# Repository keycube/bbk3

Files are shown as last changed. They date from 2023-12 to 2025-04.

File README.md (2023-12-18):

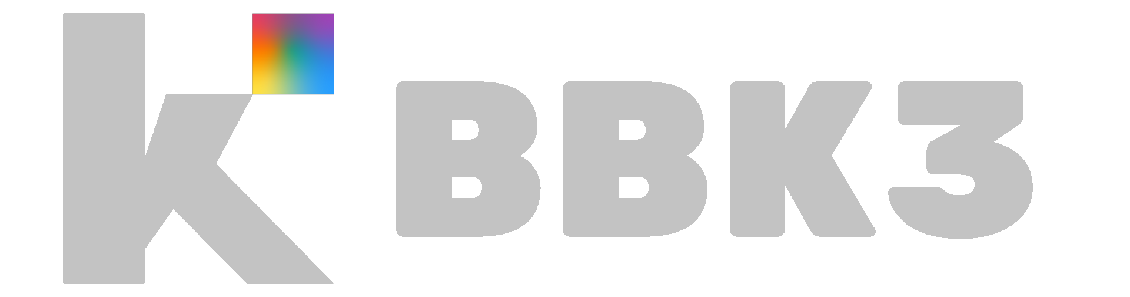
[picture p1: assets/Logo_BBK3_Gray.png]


# Introduction

The BBK3 (BabyCube) is the miniature derivative of the K3. Thanks to these 5 keys, its gyroscope and accelerator, you can control a multitude of applications thanks to its bluetooh connection.

# 3D model

The 3D models were made with Fusion 360. The models have been tested with a resin printer but are intended for an FDM printer. (The colors are present to facilitate the 3D preview, you are free to choose when printing.)

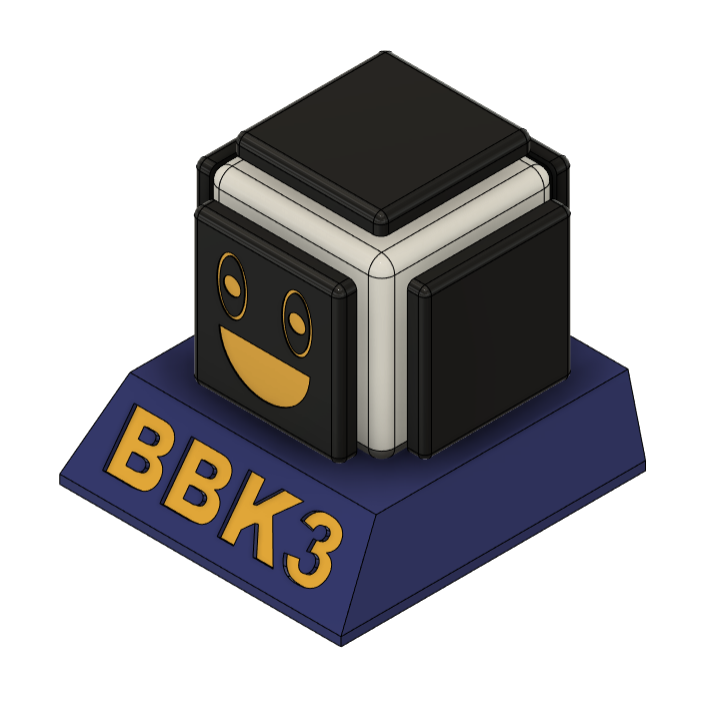
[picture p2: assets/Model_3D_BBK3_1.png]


**Below**

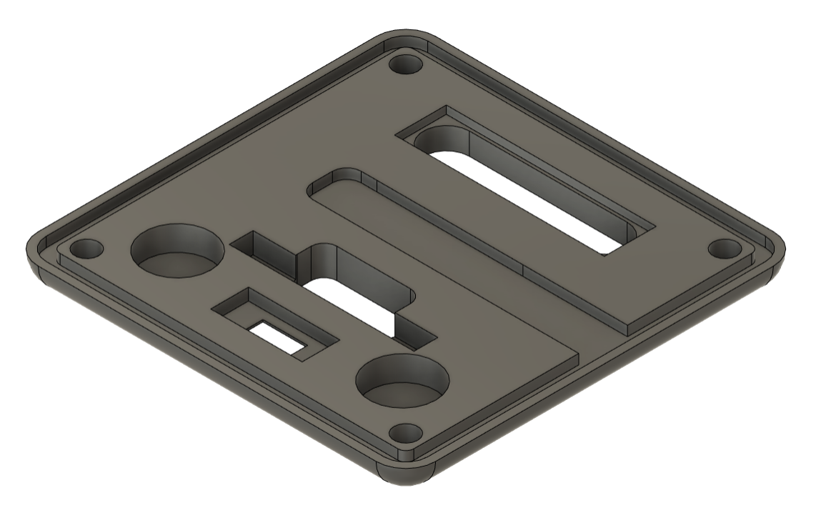
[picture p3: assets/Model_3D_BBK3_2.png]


**Above**

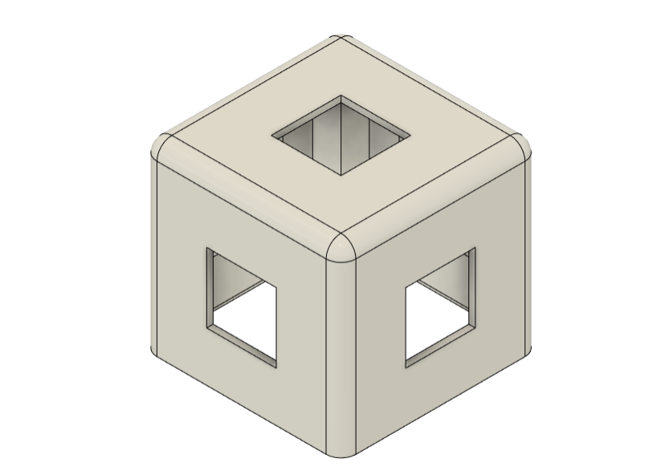
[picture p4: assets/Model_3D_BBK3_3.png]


**Support**

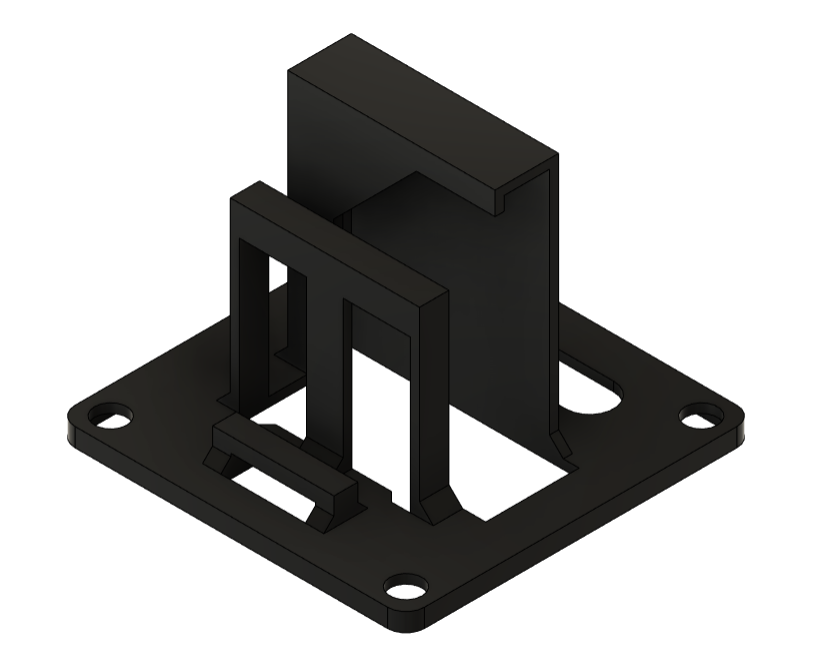
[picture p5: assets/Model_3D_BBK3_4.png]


**Keys**

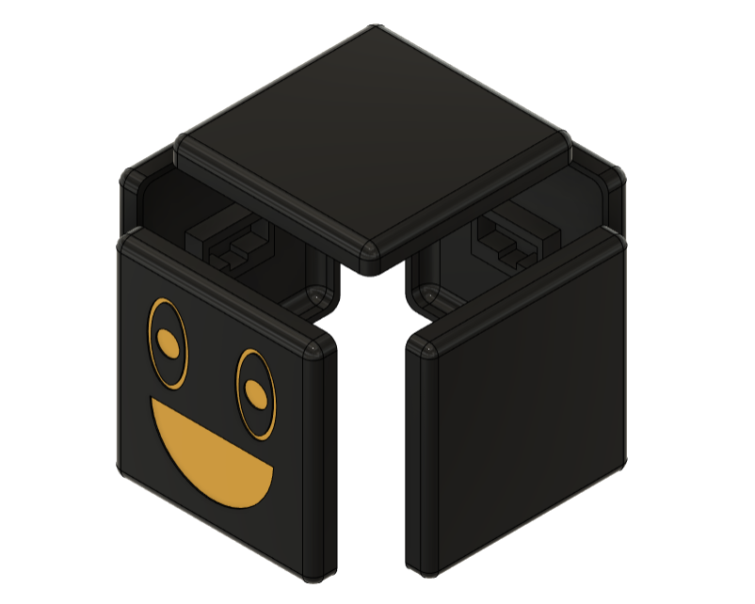
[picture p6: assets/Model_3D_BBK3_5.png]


# Electronic components

The components listed below were chosen according to our desires, the dimensions in the 3D models were made accordingly. If you want to choose other electronic components, don't forget to modify the 3D models.

**Microcontroller**: https://www.seeedstudio.com/Seeed-XIAO-BLE-Sense-nRF52840-p-5253.html

**Magnetic connection**: https://www.adafruit.com/product/5413

**Battery**: https://www.adafruit.com/product/1317

**Keys**: https://www.adafruit.com/product/5113

**Keys Sockets**: https://www.adafruit.com/product/5756

**Magnets**: https://www.amazon.fr/Deryun-aimants-puissants-n%C3%A9odyme-r%C3%A9frig%C3%A9rateur/dp/B0936VD5N4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

# Tutorial

..._TODO_...

# Code

To code, I used the Arduino IDE. I coded the code "BBK3.ino" as an example.

**- Connection**: The microcontroller creates a Bluetooth connection to be able to connect.

**- Light animation**: The cube flashes red until it is connected and reacts green once it is. When the keys are not pressed, the LEDs are orange and when a key is clicked, the corresponding key is white. After 7 seconds without clicking, the keys turn red and create the animation of a beating heart, returning to normal at the slightest click.

**- Actuators**: The gyroscope is used to move the mouse. The keys simulate the keyboard with Z, Q, S, D and left click on the top key.

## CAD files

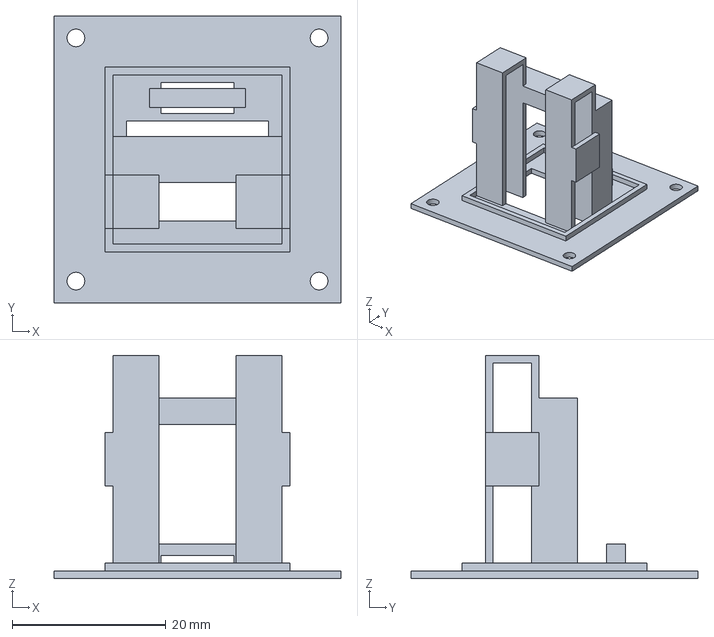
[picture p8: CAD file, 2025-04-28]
assets/models/FreeCad/bbk3_inside.FCStd
37.3 x 37.3 x 29.0 mm

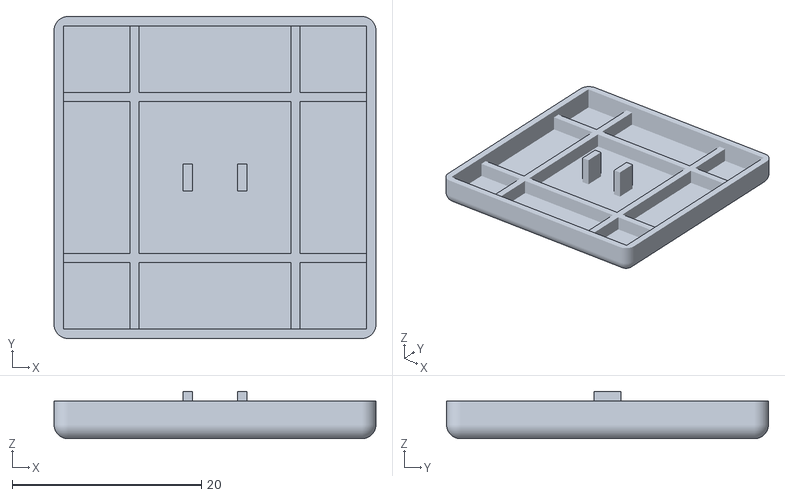
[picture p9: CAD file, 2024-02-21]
assets/models/OpensCad/keycap.stl
34.0 x 34.0 x 5.00

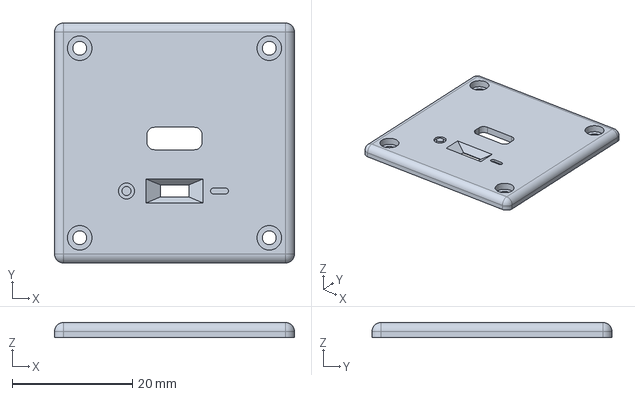
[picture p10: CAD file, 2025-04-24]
assets/models/FreeCad/bbk3_bottom.FCStd
40.0 x 40.0 x 2.50 mm

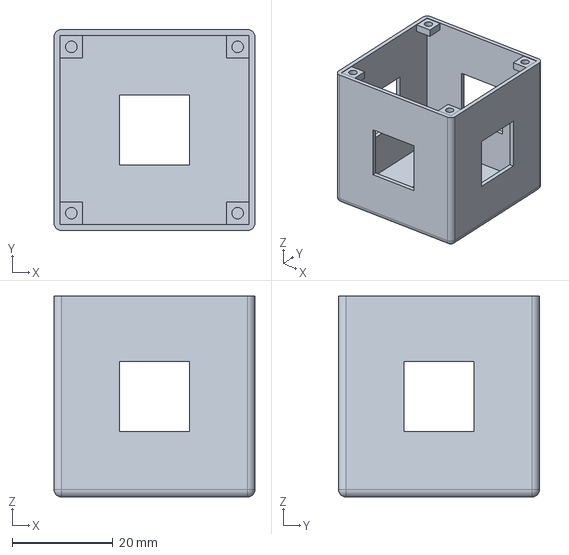
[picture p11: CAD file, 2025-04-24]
assets/models/FreeCad/bbk3_body.FCStd
40.0 x 40.0 x 40.0 mm

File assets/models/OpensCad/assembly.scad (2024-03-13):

use <body.scad>
use <bottom.scad>

x = 40;
y = 40;
z = 40;
radius = 1.5;
thickness = 1.2;
hole = 14;

innerRadius = 1.1;
outerRadius = 1.8;
spacing = 1.2+1.2; // thickness + (3 - outerRadius)

body([x, y, z], radius, thickness, hole);
translate([0, 0, 20-2.5])
    bottom([x, y, 2.5], radius, innerRadius, outerRadius, spacing);

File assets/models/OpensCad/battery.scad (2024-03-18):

use <utils/cube_rounded_side.scad>

module battery() {
    cube_rounded_side([4, 20, 28], true, 1);
}

battery();

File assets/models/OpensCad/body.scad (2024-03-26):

use <utils/cube_rounded.scad>
use <utils/mirror_copy.scad>
use <nutholder.scad>

x = 40;
y = 40;
z = 40;
radius = 1.5;
thickness = 1.2;
hole = 14;

module body(size, radius, thickness = 1.2, hole = 14) {
    width = size[0];
    depth = size[1];
    height = size[2];
    
    union() {
        difference() {
            cube_rounded([width, depth, height], true, radius);
            
            translate([0, 0, height/2])
                cube([width+0.1, depth+0.1, radius*2], true);
            
            translate([0, 0, thickness])
                cube([width-thickness*2, depth-thickness*2, height], true);
            
            cube([width+0.1, hole, hole], true);
            cube([hole, depth+0.1, hole], true);
            cube([hole, hole, height+0.1], true);
            
            translate([0, 0, height/2-radius])
                cube([width+0.1, depth+0.1, 2*1], true); // remove 1 mm
        }
        
        nh_radius = 1.15;
        nh_size = 4.5;
        nh_height = 2;
        mirror_copy([1, 0, 0])
            mirror_copy([0, 1, 0])
                translate([
                    width/-2+(nh_size+1.5)/2+thickness, 
                    depth/2-(nh_size+1.5)/2-thickness, 
                    height/2-radius-(nh_height+2)/2-2-0.1
                ]) // UPDATE here (bad const related to nutholder)
                    nutholder(nh_radius, nh_size, nh_height);
    }
}

body([x, y, z], radius, thickness, hole);

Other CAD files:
assets/models/OpensCad/bottom.scad
assets/models/OpensCad/inside.scad
assets/models/OpensCad/keycap.scad
assets/models/OpensCad/nutholder.scad
assets/models/OpensCad/pcb_SeeedStudioXIAO.scad
assets/models/OpensCad/switch.scad
assets/models/OpensCad/utils/cube_rounded.scad
assets/models/OpensCad/utils/cube_rounded_side.scad
assets/models/OpensCad/utils/mirror_copy.scad

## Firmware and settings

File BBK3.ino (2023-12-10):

#include <Adafruit_NeoPixel.h>
#include <BLE52_Mouse_and_Keyboard.h>
#include "LSM6DS3.h"
#include "Wire.h"

// Instantiate the IMU (Inertial Measurement Unit) object
LSM6DS3 myIMU(I2C_MODE, 0x6A);

// Define pin numbers for the LEDs and their corresponding directions
#define LED_PIN 0
#define NORTH 1
#define EAST 2
#define SOUTH 3
#define WEST 4
#define TOP 5

// Define the total number of LEDs
#define LED_COUNT 5

// Instantiate the NeoPixel object for controlling LEDs
Adafruit_NeoPixel pixel(LED_COUNT, LED_PIN, NEO_GRB + NEO_KHZ800);

// Array to store the state of buttons before the current iteration
int stateBefore[] = {0, 0, 0, 0, 0};

// Variable to store the timestamp before sleep
unsigned long tmpBefore1 = 0;

// Flag to indicate whether the device is in sleep mode
bool sleep = 0;

// Function to check if the keyboard is connected and provide visual feedback
void isConnectedMK3() {
  if (!Keyboard.isConnected()) {
    // Blink red lights indicating disconnection
    for (int i = 0; i < LED_COUNT; i++) {
      pixel.setPixelColor(i, pixel.Color(255, 0, 0));
      pixel.show();
      delay(50);
    }
    // Turn off the LEDs
    for (int i = 0; i < LED_COUNT; i++) {
      pixel.setPixelColor(i, pixel.Color(0, 0, 0));
      pixel.show();
      delay(50);
    }
  }

  if (Keyboard.isConnected()) {
    // Blink green lights indicating connection
    for (int i = 0; i < LED_COUNT; i++) {
      pixel.setPixelColor(i, pixel.Color(0, 255, 0));
    }
    pixel.show();
    delay(50);
    // Turn off the LEDs
    for (int i = 0; i < LED_COUNT; i++) {
      pixel.setPixelColor(i, pixel.Color(0, 0, 0));
    }
    pixel.show();
    delay(50);
  }
}

// Function to create a pulsating effect to indicate sleep mode
void isSleep(int pulsationSpeed) {
  static unsigned long dernierChangement = 0;
  static int intensite = 0;
  static bool monte = true;

  unsigned long maintenant = millis();

  if (maintenant - dernierChangement >= pulsationSpeed) {
    dernierChangement = maintenant;
    if (monte) {
      intensite = (intensite + 1) % 256;
      if (intensite == 100) {
        monte = false;
      }
    } else {
      intensite = (intensite - 1 + 256) % 256;
      if (intensite == 0) {
        monte = true;
      }
    }
    // Set the LED colors based on intensity for pulsating effect
    for (int i = 0; i < LED_COUNT; i++) {
      pixel.setPixelColor(i, pixel.Color(intensite, 0, 0));
    }
  }
}

void setup() {
  Serial.begin(115200);

  // Set pin modes for the directional buttons
  pinMode(NORTH, INPUT_PULLUP);
  pinMode(EAST, INPUT_PULLUP);
  pinMode(SOUTH, INPUT_PULLUP);
  pinMode(WEST, INPUT_PULLUP);
  pinMode(TOP, INPUT_PULLUP);

  // Initialize the NeoPixel strip
  pixel.begin();
  pixel.show();
  pixel.setBrightness(255);

  // Initialize the keyboard
  Keyboard.begin();

  // Check if the IMU device is connected
  if (myIMU.begin() != 0) {
    Serial.println("Device error");
  } else {
    Serial.println("Device OK!");
  }
}

void loop() {
  // Move the mouse based on gyroscope readings
  Mouse.move((myIMU.readFloatGyroX() / 2), -(myIMU.readFloatGyroY() / 2));

  // Check and display connection status
  while (!Keyboard.isConnected()) {
    isConnectedMK3();
  }

  // Activate sleep mode after 7 seconds of inactivity
  if (millis() - tmpBefore1 > 7000) {
    sleep = 1;
  }

  if (sleep == 1) {
    // Pulsating effect during sleep
    isSleep(1);
    pixel.show();
    for (int i = 0; i < LED_COUNT; i++) {
      // Check for button press to wake up
      if (digitalRead(i + 1) == 0) {
        tmpBefore1 = millis();
        sleep = 0;
      }
    }
  } else {
    Serial.println(millis() - tmpBefore1);

    // Handle button presses for movement and mouse click
    for (int i = 0; i < LED_COUNT; i++) {
      if (digitalRead(i + 1) == 0) {
        tmpBefore1 = millis();
        pixel.setPixelColor(i, pixel.Color(255, 255, 255));
        pixel.show();
        // Handle button press actions
        if (i == 0) {
          if (stateBefore[i] == 0) {
            Keyboard.press('w');
            stateBefore[i] = 1;
          }
        }
        if (i == 1) {
          if (stateBefore[i] == 0) {
            Keyboard.press('d');
            stateBefore[i] = 1;
          }
        }
        if (i == 2) {
          if (stateBefore[i] == 0) {
            Keyboard.press('s');
            stateBefore[i] = 1;
          }
        }
        if (i == 3) {
          if (stateBefore[i] == 0) {
            Keyboard.press('a');
            stateBefore[i] = 1;
          }
        }
        if (i == 4) {
          if (stateBefore[i] == 0) {
            Mouse.click(MOUSE_LEFT);
            stateBefore[i] = 1;
          }
        }
      } else {
        // Handle button release actions
        pixel.setPixelColor(i, pixel.Color(128, 64, 0));
        pixel.show();
        if (i == 0) {
          if (stateBefore[i] == 1) {
            Keyboard.release('w');
            stateBefore[i] = 0;
          }
        }
        if (i == 1) {
          if (stateBefore[i] == 1) {
            Keyboard.release('d');
            stateBefore[i] = 0;
          }
        }
        if (i == 2) {
          if (stateBefore[i] == 1) {
            Keyboard.release('s');
            stateBefore[i] = 0;
          }
        }
        if (i == 3) {
          if (stateBefore[i] == 1) {
            Keyboard.release('a');
            stateBefore[i] = 0;
          }
        }
        if (i == 4) {
          if (stateBefore[i] == 1) {
            Mouse.release(MOUSE_LEFT);
            stateBefore[i] = 0;
          }
        }
      }
    }
  }
}

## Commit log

2024-02-14 Start converting 3D models to OpenSCAD (add rounded cube module)
    [cube_rounded.scad]
2024-02-16 Add keycap solidification
    [keycap.scad]
2024-02-16 add keycap insertion parts
    [keycap.scad]
2024-02-17 Add customizer parameters to cube_rounded
    [cube_rounded.scad]
2024-02-21 Fix spacing between insertion parts
    [keycap.scad]
2024-02-21 Reverse the model (upside down)
    [keycap.scad]
2024-02-21 Decrease height of solidification
    [keycap.scad]
2024-02-21 Create keycap module
    [keycap.scad]
2024-02-21 Add thickness parameter
    [keycap.scad]
2024-02-21 Use thickness parameter to reduce size of solidification overflow
    [keycap.scad]
2024-02-21 Fix (use of radius parameter)
    [keycap.scad]
2024-02-21 add insertHeight parameter
    [keycap.scad]
2024-02-21 Increase insert width and spacing
    [keycap.scad]
2024-02-21 add insertSpacing, insertWidth and insertDepth variables
    [keycap.scad]
2024-02-21 add customizer parameters to keycap
    [keycap.scad]
2024-02-21 Add STL format to keycap (34x34x4mm, 1.5 radius)
    [keycap.stl]
2024-03-04 Create body module
    [body.scad]
2024-03-13 Add parameters to nutholder
    [nutholder.scad]
2024-03-13 Add more control over diameter (nutholder)
    [nutholder.scad]
2024-03-13 add nut holders and remove 1mm to place the inner structure to the body
    [body.scad]
2024-03-13 Switch parameters order in body.scad
    [body.scad]
2024-03-13 Update nutholder (use radius instead of diameter and reverse rotation)
    [nutholder.scad]
2024-03-13 Update body (use radius value for nutholder and replace with reverse rotation)
    [body.scad]
2024-03-13 Update bottom (use only spacing to position the holes from borders)
    [bottom.scad]
2024-03-14 Update pcb_SeeedStudioXIAO (now use cube_rounded_side)
    [pcb_SeeedStudioXIAO.scad]
2024-03-14 Update battery (use cube_rounded_side)
    [battery.scad]
2024-03-14 Swap center and radius parameters order for cube_rounded_side
    [battery.scad, cube_rounded_side.scad, pcb_SeeedStudioXIAO.scad]
2024-03-14 Create inside.scad including battery cover
    [inside.scad]
2024-03-15 Update inside.scad (add pcb cover)
    [inside.scad]
2024-03-15 Update inside (add switch cover)
    [inside.scad]
2024-03-15 Update inside (increase size of pcb cover)
    [inside.scad]
2024-03-15 Update inside (position all covers)
    [inside.scad]
2024-03-15 Update bottom (add pcb, switch and battery holes)
    [bottom.scad]
2024-03-15 Update bottom (use mirror_copy for the screw holes)
    [bottom.scad]
2024-03-15 Update bottom (add holes for magnets)
    [bottom.scad]
2024-03-15 Update inside (add body for assembly checking)
    [inside.scad]
2024-03-18 Increase size of battery
    [battery.scad]
2024-03-18 Update bottom (increase size of outerRadius/screwhead and magnetRadius)
    [bottom.scad]
2024-03-23 Update bottom (slightly increase magnet placeholder thickness)
    [bottom.scad]
2024-03-23 Update nutholder (increase entrance and screw hole)
    [nutholder.scad]
2024-03-23 Update bottom (increase inner/outer radius; ie screw hole/head))
    [bottom.scad]
2024-03-23 Update body (with new nutholder size)
    [body.scad]
2024-03-23 Update inside (move comments, increase screw holes)
    [inside.scad]
2024-03-26 Increase height (1 mm) of the body (to hide the inside part) and slightly decrease height of nutholders (0.1 mm)
    [body.scad]
2024-03-26 Decrease size of the inside plane (to hide it)
    [inside.scad]
2024-03-30 Update inside (slightly decrease main structure size)
    [inside.scad]
2024-03-30 Update bottom (add ON/OFF iconography)
    [bottom.scad]
2024-03-31 Update inside (slightly decrease PCB cover)
    [inside.scad]
2024-03-31 Update inside (add fortification)
    [inside.scad]
2024-03-31 Update inside (strengthen PCB cover top flat/side)
    [inside.scad]
2025-04-24 FreeCad Body & Bottom
    [assembly.scad, battery.scad, bbk3_body.FCStd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]
2025-04-28 Model inside FreeCad
    [bbk3_inside.FCStd, bottom.scad]
